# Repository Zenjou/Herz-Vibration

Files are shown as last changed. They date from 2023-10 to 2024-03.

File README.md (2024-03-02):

# Herz Vibration
Project for Electronic Equipment Design Course ( ELO301 Federico Santa María Technical University)

Group 6 
 - Victor Muñoz Salinas
 - Josefa Gomez
 - Diego Muñoz
 - Maximiliano Lara

# Description:
This project focuses on designing a PCB for real-time seismocardiograms utilizing geophones. Geophones efficiently capture vibrations produced by cardiac activity (Seismocardiography) . The custom-designed PCB seamlessly integrates with existing software, enabling efficient signal processing and in-depth analysis. Eagle PCB schematics, manufacturing files (including Gerber files and drill files), and a comprehensive Bill of Materials (BOM) are provided for straightforward replication.

# Features:
Custom-designed PCB optimized for seamless integration with geophones.

Eagle PCB schematics for a thorough understanding and easy modification.

Inclusion of all essential manufacturing files, including Gerber files and drill files, for PCB fabrication.

Utilizes the STM32 NUCLEO-L452 development board for enhanced functionality.

# Technologies Used:
Eagle PCB for schematic design.

Geophonic sensors for vibration capture (3 Geophones for each axis).

STM32 NUCLEO-L452 development board.

**SerialPlot by Hasan Yavuz Özderya for graphical visualization.**

ADS131M03 3-channel, 24-bit, 64 kSPS simultaneous sampling delta-sigma ADC.

# Files:
Eagle PCB Schematics

Manufacturing Files (Gerber, Drill Files, etc.)

BOM File

Videos

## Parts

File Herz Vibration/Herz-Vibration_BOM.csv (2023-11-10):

Part | Value | Device | Package | Description | ARROW_PART_NUMBER | ARROW_PRICE-STOCK | DESCRIPTION | HEIGHT | MANUFACTURER_NAME | MANUFACTURER_PART_NUMBER | MOUSER_PART_NUMBER | MOUSER_PRICE-STOCK | PARTNO | POPULARITY | SPICEPREFIX
C1 | 1uF | C-USC0805 | C0805 | CAPACITOR, American symbol |  |  |  |  |  |  |  |  | C1206C105K3RAC7215 | 63 | C
C2 | 220nF | C-USC0805 | C0805 | CAPACITOR, American symbol |  |  |  |  |  |  |  |  | 885382207008 | 63 | C
C3 | 1uF | C-USC0805 | C0805 | CAPACITOR, American symbol |  |  |  |  |  |  |  |  | C1206C105K3RAC7215 | 63 | C
IC1 | AD8574TRUZ-EP | AD8574TRUZ-EP | SOP65P640X120-14N | Amplificateurs oprationnels - Amplis-Op QUAD PRECISION RAIL RAIL CHOPPER OP AMP | AD8574TRUZ-EP | https://www.arrow.com/en/products/ad8574truz-ep/analog-devices?region=nac | Amplificateurs oprationnels - Amplis-Op QUAD PRECISION RAIL RAIL CHOPPER OP AMP | 1.2mm | Analog Devices | AD8574TRUZ-EP | 584-AD8574TRUZ-EP | https://www.mouser.co.uk/ProductDetail/Analog-Devices/AD8574TRUZ-EP?qs=wUXugUrL1qxNfkZ2pBeSrA%3D%3D
IC2 | ADS131M03IPWR | ADS131M03IPWR | SOP65P640X120-20N | Analog to Digital Converters - ADC 24-bit, 32-kSPS, 3-channel, simultaneous-sampling, delta-sigma ADC |  |  | Analog to Digital Converters - ADC 24-bit, 32-kSPS, 3-channel, simultaneous-sampling, delta-sigma ADC | 1.2mm | Texas Instruments | ADS131M03IPWR | 595-ADS131M03IPWR | https://www.mouser.co.uk/ProductDetail/Texas-Instruments/ADS131M03IPWR?qs=Jslch3jnSjnSosXolUzTvg%3D%3D
J1 | 009276006021106 | 009276006021106 | 009276006021106 | AVX INTERCONNECT - 009276006021106 - CONNECTOR, IDC, 6 WAY, 18 AWG | 009276006021106 | https://www.arrow.com/en/products/009276006021106/avx?region=nac | AVX INTERCONNECT - 009276006021106 - CONNECTOR, IDC, 6 WAY, 18 AWG | 5mm | AVX | 009276006021106 | 581-009276006021106 | https://www.mouser.co.uk/ProductDetail/AVX/009276006021106?qs=QtI0yD1FyOMc2fy6i4jFlw%3D%3D
LED1 | 150060GS75000 | 150060GS75000 | LEDC1608X80N | Wurth Elektronik WL-SMCW 520 nm Green LED, 1608 (0603) Clear SMD package |  |  | Wurth Elektronik WL-SMCW 520 nm Green LED, 1608 (0603) Clear SMD package | 0.8mm | Wurth Elektronik | 150060GS75000 | 710-150060GS75000 | https://www.mouser.co.uk/ProductDetail/Wurth-Elektronik/150060GS75000?qs=LlUlMxKIyB0UYkq5lDO8nA%3D%3D
M1 |  | NUCLEO-L452RE | NUCLEO-64 | No existe un outline (Layer Dimension) para esta librería. En su lugar se utilizó una referencia en tDocu.
R1 | 1k | R-US_R0805 | R0805 | RESISTOR, American symbol |  |  |  |  |  |  |  |  | TNPW04021K15BYEP | 85 | R
R2 | 2k2 | R-US_R0805 | R0805 | RESISTOR, American symbol |  |  |  |  |  |  |  |  | RP0603BRD072K2L | 85 | R
R3 | 1k | R-US_R0805 | R0805 | RESISTOR, American symbol |  |  |  |  |  |  |  |  | TNPW04021K15BYEP | 85 | R
R4 | 2k2 | R-US_R0805 | R0805 | RESISTOR, American symbol |  |  |  |  |  |  |  |  | RP0603BRD072K2L | 85 | R
R5 | 1k | R-US_R0805 | R0805 | RESISTOR, American symbol |  |  |  |  |  |  |  |  | TNPW04021K15BYEP | 85 | R
R6 | 2k2 | R-US_R0805 | R0805 | RESISTOR, American symbol |  |  |  |  |  |  |  |  | RP0603BRD072K2L | 85 | R
R7 | 1k | R-US_R0805 | R0805 | RESISTOR, American symbol |  |  |  |  |  |  |  |  | TNPW04021K15BYEP | 85 | R
R8 | 2k2 | R-US_R0805 | R0805 | RESISTOR, American symbol |  |  |  |  |  |  |  |  | RP0603BRD072K2L | 85 | R
R9 | 12 | R-US_R0805 | R0805 | RESISTOR, American symbol |  |  |  |  |  |  |  |  | RT0603DRE0712RL | 85 | R

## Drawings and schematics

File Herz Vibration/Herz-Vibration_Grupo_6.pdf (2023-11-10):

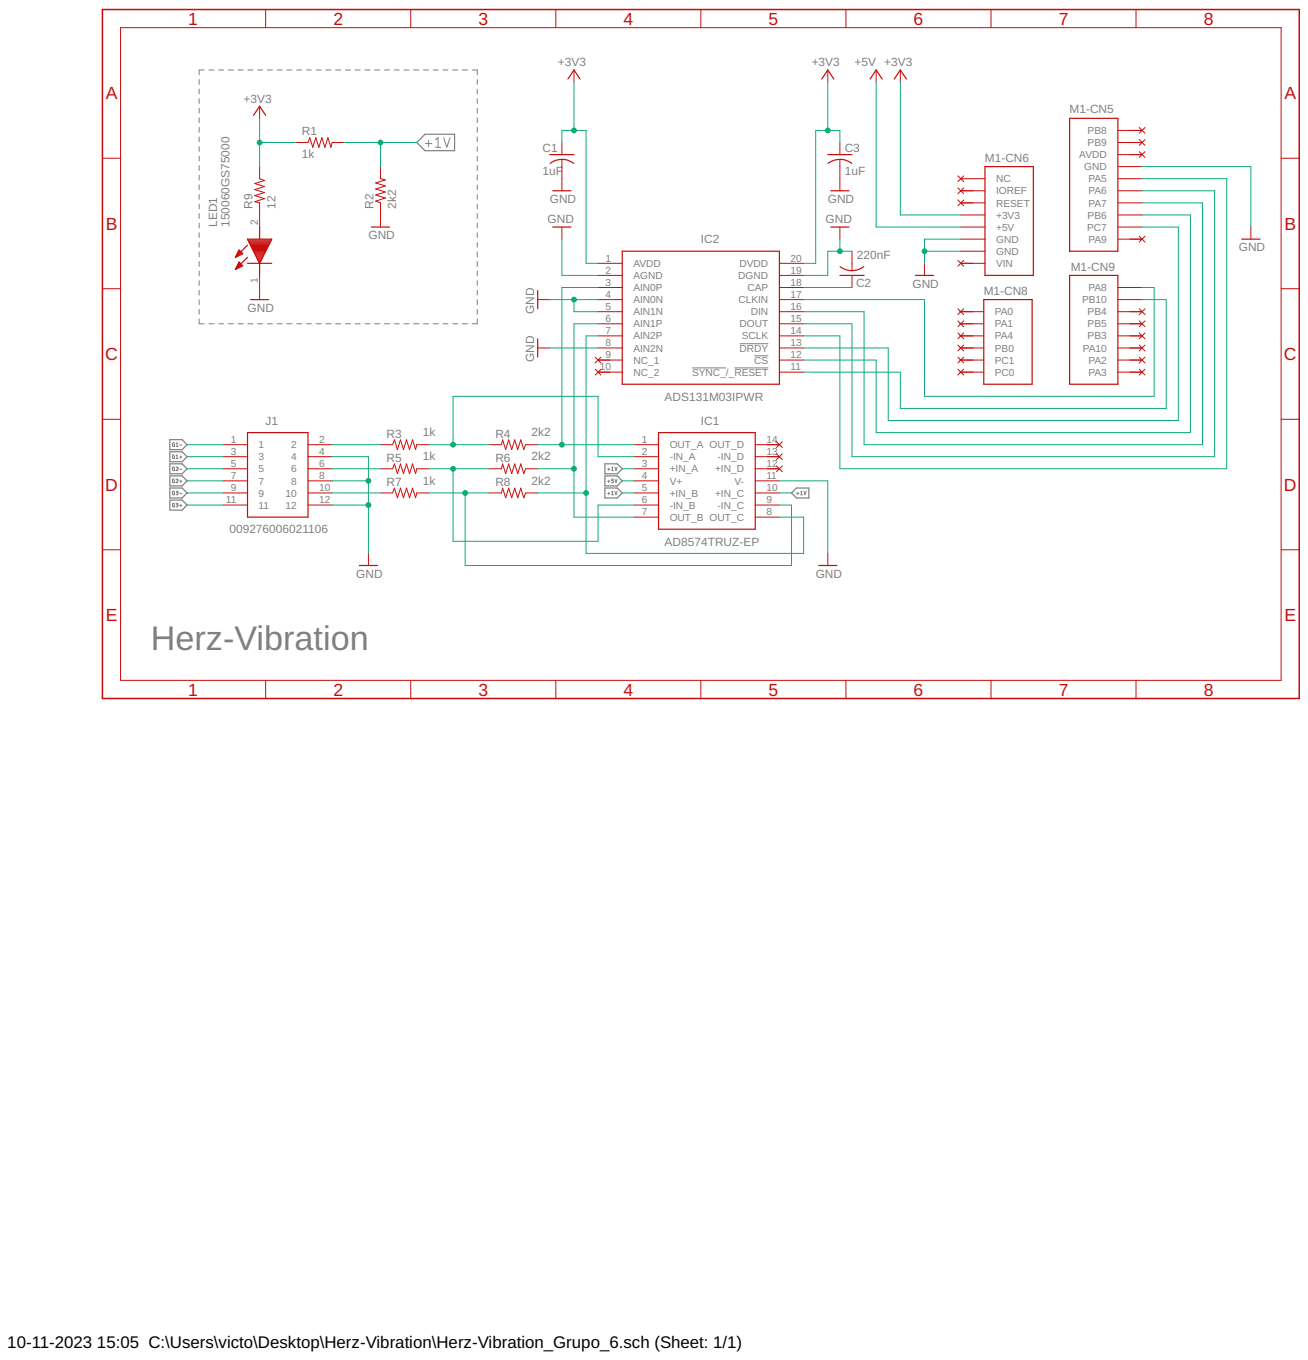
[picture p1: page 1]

10-11-2023 15:05 C:\Users\victo\Desktop\Herz-Vibration\Herz-Vibration_Grupo_6.sch (Sheet: 1/1)

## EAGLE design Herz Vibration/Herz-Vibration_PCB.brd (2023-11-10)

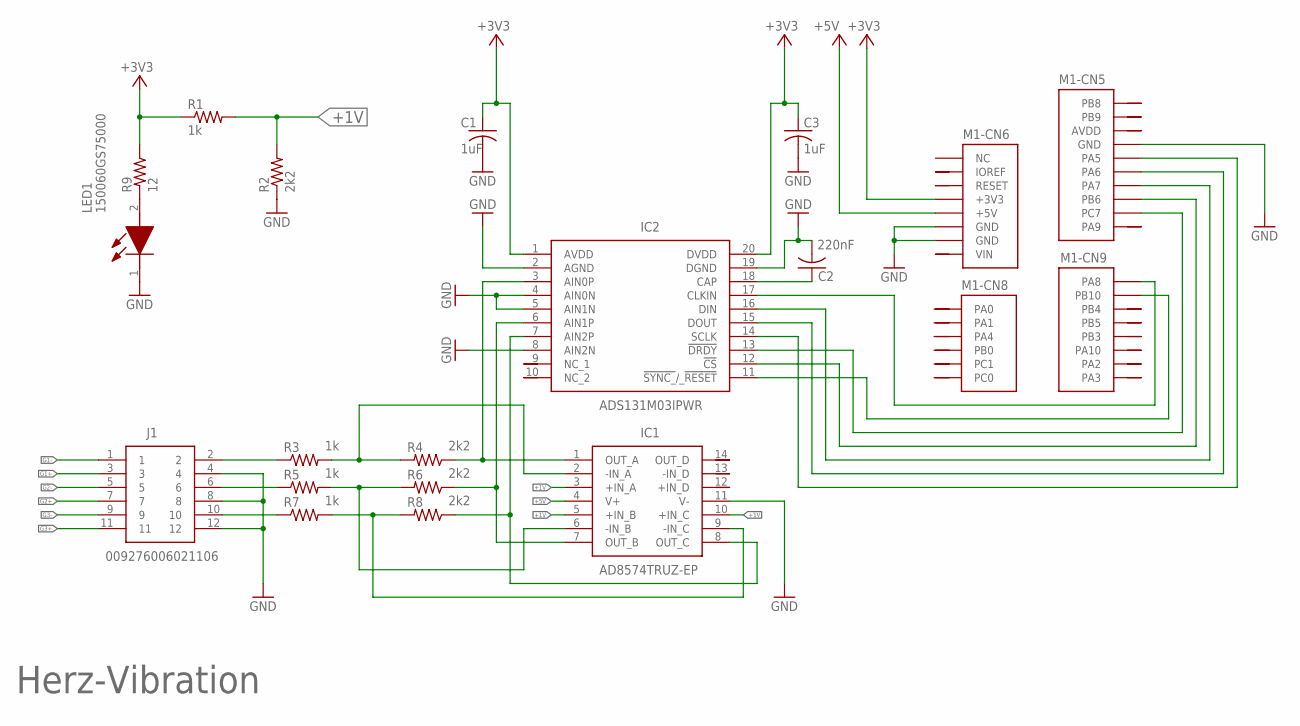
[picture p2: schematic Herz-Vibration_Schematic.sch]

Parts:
C1, C3: 1uF; C0805; PARTNO C1206C105K3RAC7215
C2: 220nF; C0805; PARTNO 885382207008
IC1: AD8574TRUZ-EP; SOP65P640X120-14N
IC2: ADS131M03IPWR; SOP65P640X120-20N
J1: 009276006021106
LED1: 150060GS75000; LEDC1608X80N
M1: NUCLEO-L452RE; NUCLEO-64
R1, R3, R5, R7: 1k; R0805; PARTNO TNPW04021K15BYEP
R2, R4, R6, R8: 2k2; R0805; PARTNO RP0603BRD072K2L
R9: 12; R0805; PARTNO RT0603DRE0712RL

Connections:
+1V: IC1.3 (+IN_A), IC1.5 (+IN_B), IC1.10 (+IN_C), R1.2, R2.2
+3V3: C1.1, C3.1, IC2.1 (AVDD), IC2.20 (DVDD), M1.CN6-4 (+3V3), M1.CN7-16 (+3V3), R1.1, R9.1
+5V: IC1.4 (V+), M1.CN6-5 (+5V), M1.CN7-18 (+5V)
AGND: M1.CN10-32 (AGND)
AVDD: M1.CN10-7 (AVDD)
G1+: J1.3
G1-: J1.1
G2+: J1.7
G2-: J1.5
G3+: J1.11
G3-: J1.9
GND: C1.2, C2.2, C3.2, IC1.11 (V-), IC2.2 (AGND), IC2.4 (AIN0N), IC2.5 (AIN1N), IC2.8 (AIN2N), IC2.19 (DGND), J1.4, J1.8, J1.12, LED1.1 (K), M1.CN5-7 (GND), M1.CN6-6 (GND), M1.CN6-7 (GND), M1.CN7-8 (GND), M1.CN7-19 (GND), M1.CN7-20 (GND), M1.CN7-22 (GND), M1.CN10-9 (GND), M1.CN10-20 (GND), R2.1
unnamed: IC1.1 (OUT_A), IC2.3 (AIN0P), R4.1
unnamed: IC1.7 (OUT_B), IC2.6 (AIN1P), R6.1
unnamed: IC1.8 (OUT_C), IC2.7 (AIN2P), R8.1
unnamed: IC1.2 (-IN_A), R3.2, R4.2
unnamed: IC1.9 (-IN_C), R7.2, R8.2
unnamed: IC1.6 (-IN_B), R5.2, R6.2
unnamed: J1.2, R3.1
unnamed: IC2.14 (SCLK), M1.CN5-6 (PA5)
unnamed: J1.6, R5.1
unnamed: J1.10, R7.1
unnamed: IC2.13 (!DRDY), M1.CN5-2 (PC7)
unnamed: IC2.12 (!CS), M1.CN5-3 (PB6)
unnamed: LED1.2 (A), R9.2
unnamed: C2.1, IC2.18 (CAP)
unnamed: IC2.17 (CLKIN), M1.CN9-8 (PA8)
unnamed: IC2.11 (!SYNC_!/_!RESET), M1.CN9-7 (PB10)
unnamed: IC2.16 (DIN), M1.CN5-4 (PA7)
unnamed: IC2.15 (DOUT), M1.CN5-5 (PA6)
U5V: M1.CN10-8 (U5V)
VBAT: M1.CN7-33 (VBAT)
VDD: M1.CN7-5 (VDD)
VIN: M1.CN7-24 (VIN)

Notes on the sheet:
Herz-Vibration

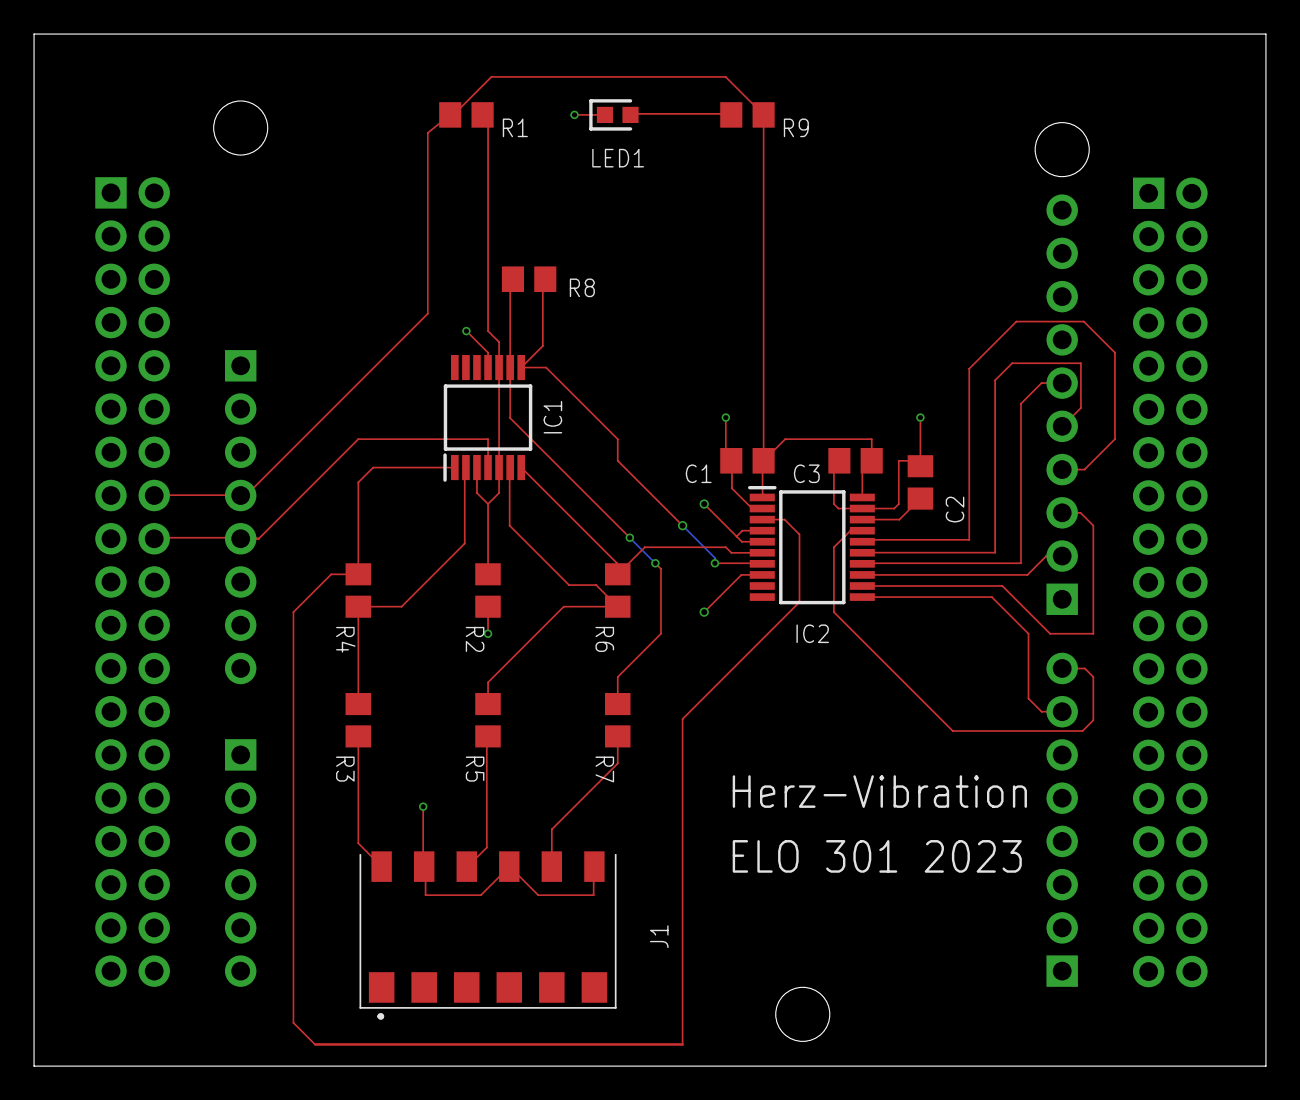
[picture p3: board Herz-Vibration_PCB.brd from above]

Board: 2 copper layers, 72.4 x 60.6 mm, 17 parts (0 on the bottom side), 22 nets.

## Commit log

2023-10-19 Project and Schematic Folder.
    [Esquemático_Grupo_6.sch]
2023-11-10 Actualización de esquemáticos y PCB.
    [BOM_Esquematico_Grupo_6.csv, Herz-Vibration_Grupo_6.brd, Herz-Vibration_Grupo_6.csv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]
2023-11-10 Rename Herz-Vibration_Grupo_6.csv to Herz-Vibration_Grupo_6_BOM.csv
    BOM
    [Herz-Vibration_Grupo_6_BOM.csv]
